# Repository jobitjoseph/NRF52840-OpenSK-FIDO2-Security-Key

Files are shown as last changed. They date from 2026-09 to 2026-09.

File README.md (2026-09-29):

# Build Your Own FIDO2 Security Key with nRF52840 and OpenSK

An open-source USB FIDO2 security key built around the **Nordic nRF52840** and **Google's OpenSK** firmware.

This project demonstrates how to build a hardware-backed authentication device that can be used with websites and services supporting **FIDO2 / WebAuthn**.

The custom hardware uses the nRF52840's native USB interface and hardware-assisted cryptography to implement the security-key functionality. The device communicates with the host computer over USB and keeps the credential's private key on the security key rather than transferring it to the computer or website.

---

## Features

- FIDO2 / WebAuthn authentication
- nRF52840-based custom hardware
- OpenSK open-source security-key firmware
- USB HID FIDO2 transport
- Hardware-assisted cryptography using the nRF52840
- Credential private key remains on the security key
- USB DFU / UF2 firmware updates
- Custom capacitive touch input for user presence
- RGB LED for status indication
- Custom compact PCB
- Open-source hardware and firmware modifications

---

## How It Works

The security key acts as a FIDO2 authenticator between the browser and the website.

During registration, the security key generates a unique credential key pair:

```text
                 Registration

Website
   │
   │ Registration request
   ▼
Browser
   │
   │ FIDO2 / CTAP2 over USB HID
   ▼
OpenSK on nRF52840
   │
   ├── Generate credential key pair
   │
   ├── Private key ──► Stored on security key
   │
   └── Public key ───► Website

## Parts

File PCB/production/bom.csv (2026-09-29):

Designator | Footprint | Quantity | Value | LCSC Part #
C1, C2, C3 | 0402 | 3 | 4.7uF | C1779
C10 | 0402 | 1 | 100pF | C1546
C11, C9 | 0402 | 2 | 1uF | C52923
C12, C13 | 0402 | 2 | 8pF | C32949
C14, C4, C5, C6, C7 | 0402 | 5 | 100nF | C14663
C15 | 0402 | 1 | 10nF | C1710
C8 | 0402 | 1 | 820pF | C1523
CR1 | TVS-SP05_LTF-L | 1 | SP0503BAHTG | C7074
J1 | SAMESKY_UP32-C-F-G-FL-1-P24 | 1 | UP32-C-F-G-FL-1-P24 | C42453853
J2 | PinHeader_1x01_P2.54mm_Vertical | 1 | Conn_01x01
R1 | 0402 | 1 | 0R | C17168
R2, R3 | 0402 | 2 | 5.1K | C25905
R4, R5, R6 | 0402 | 3 | 220R | C25091
R7 | 0402 | 1 | 10K | C25744
SW1 | SW-SMD_4P-L4.5-W4.5-P3.50-LS5.0 | 1 | TS45055A | C412371
TP1, TP2, TP3, TP4, TP5, TP6 | TestPoint_Pad_D1.0mm | 6 | TestPoint
U1 | XCVR_NRF52840-QIAA-R | 1 | NRF52840-QIAA | NRF52840-QIAA-R
U2 | SOT-23-6 | 1 | AT42QT1010-TSHR | C74512
U3 | LED-SMD_4P-L1.6-W1.5-BL-2 | 1 | XL-1615RGBC-YG | C5440642
Y1 | Crystal_SMD_2016-4Pin_2.0x1.6mm | 1 | 32MHz | C383840

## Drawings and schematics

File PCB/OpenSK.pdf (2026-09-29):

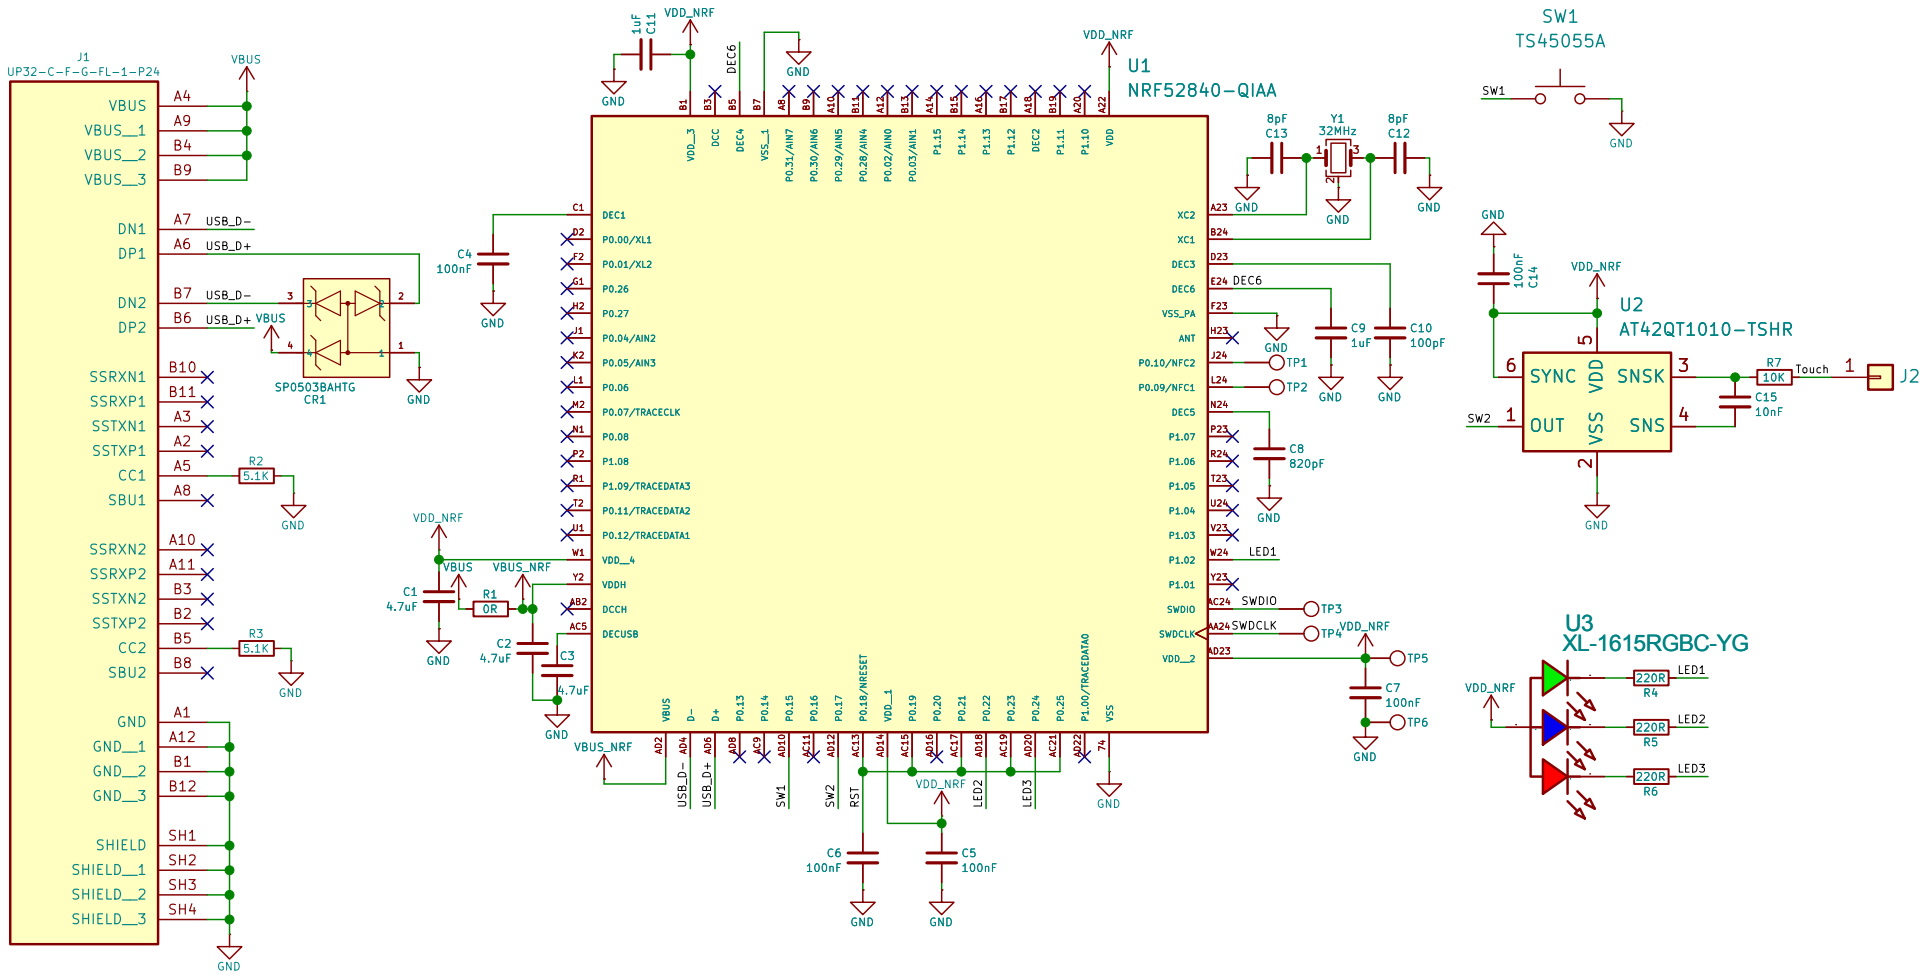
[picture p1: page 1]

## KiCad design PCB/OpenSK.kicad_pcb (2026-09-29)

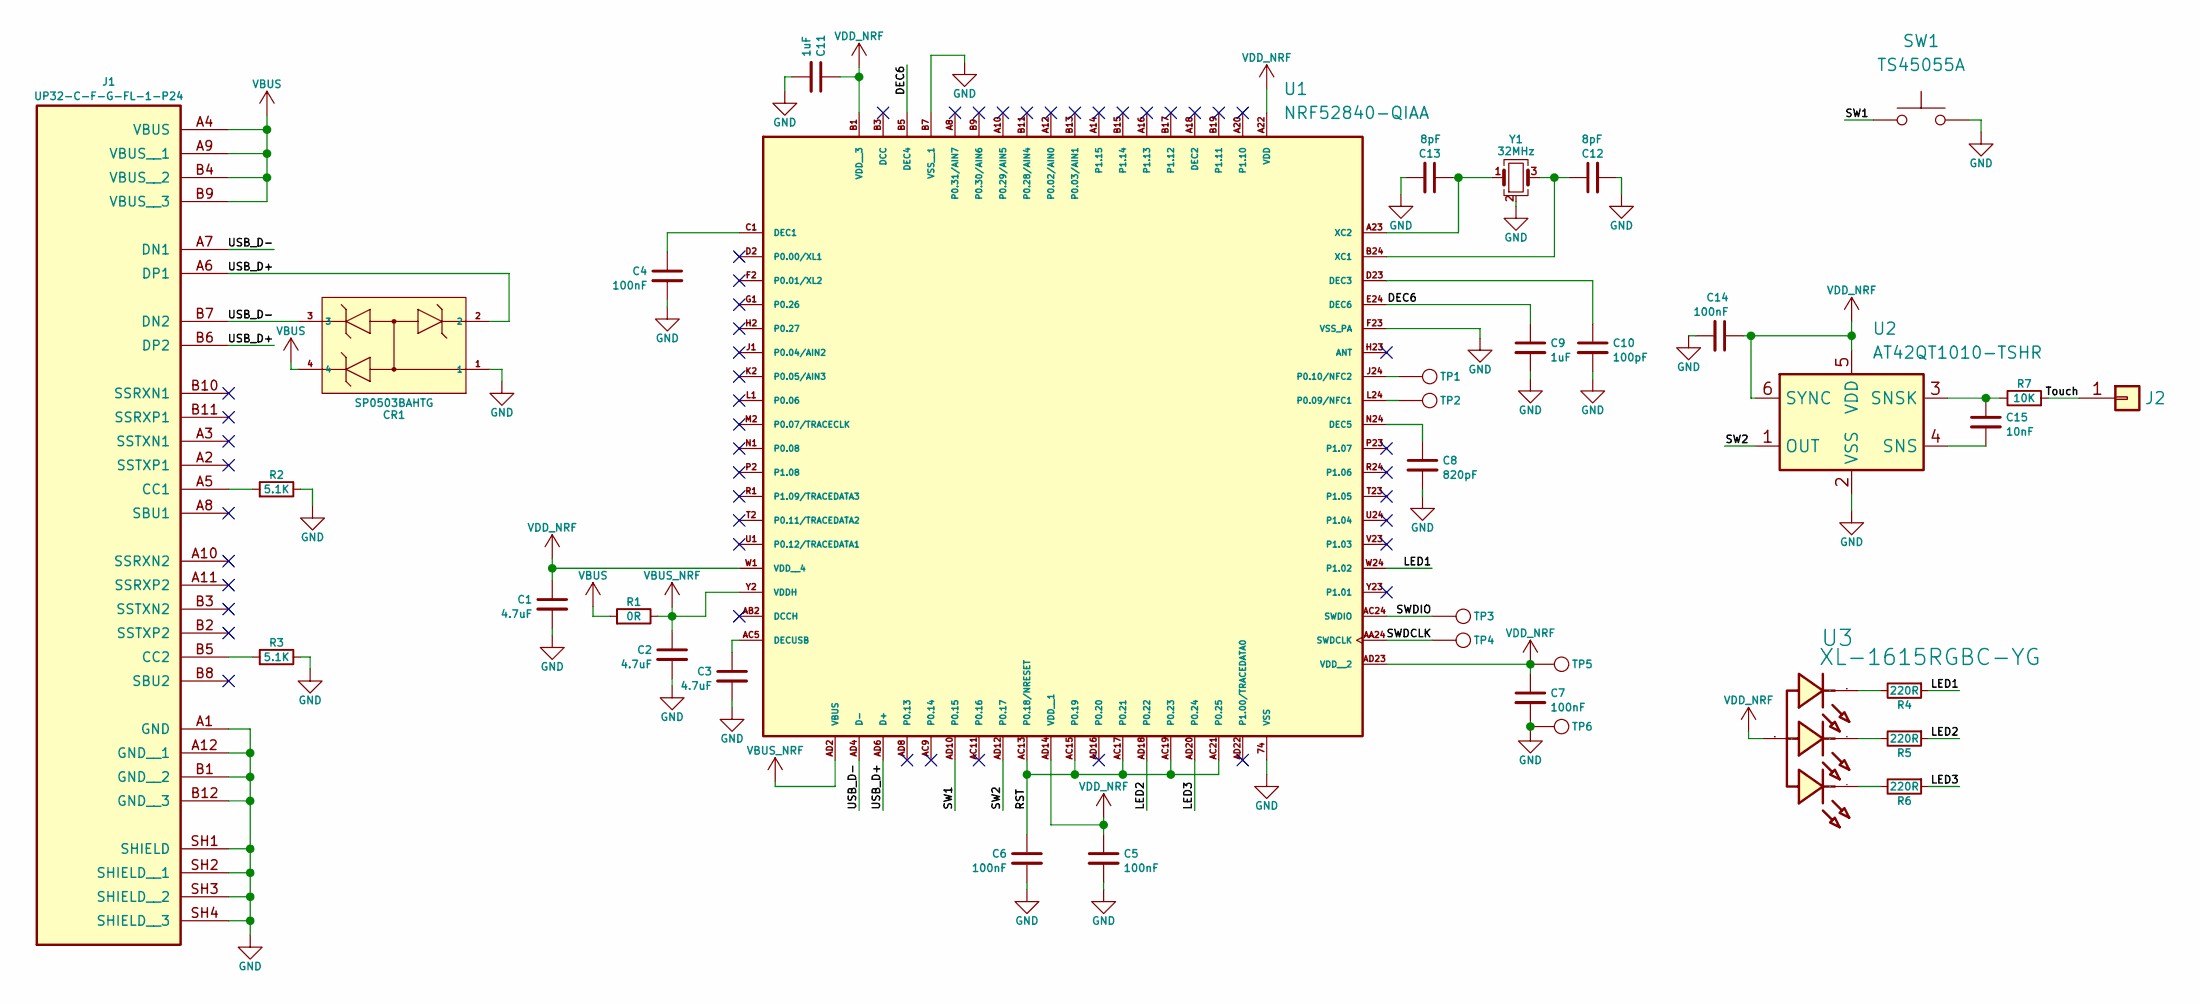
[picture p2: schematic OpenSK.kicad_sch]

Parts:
C1, C2, C3: 4.7uF; C_0402_1005Metric; LCSC Part # C1779
C4, C5, C6, C7, C14: 100nF; C_0402_1005Metric; LCSC Part # C14663
C8: 820pF; C_0402_1005Metric; LCSC Part # C1523
C9, C11: 1uF; C_0402_1005Metric; LCSC Part # C52923
C10: 100pF; C_0402_1005Metric; LCSC Part # C1546
C12, C13: 8pF; C_0402_1005Metric; LCSC Part # C32949
C15: 10nF; C_0402_1005Metric; LCSC Part # C1710
CR1: SP0503BAHTG; TVS-SP05_LTF-L; LCSC Part # C7074
J1: UP32-C-F-G-FL-1-P24; SAMESKY_UP32-C-F-G-FL-1-P24; PARTREV 1.01; LCSC Part # C42453853
J2: Conn_01x01; PinHeader_1x01_P2.54mm_Vertical
R1: 0R; R_0402_1005Metric; LCSC Part # C17168
R2, R3: 5.1K; R_0402_1005Metric; LCSC Part # C25905
R4, R5, R6: 220R; R_0402_1005Metric; LCSC Part # C25091
R7: 10K; R_0402_1005Metric; LCSC Part # C25744
SW1: TS45055A; SW-SMD_4P-L4.5-W4.5-P3.50-LS5.0; LCSC Part # C412371
TP1, TP2, TP3, TP4, TP5, TP6: TestPoint; TestPoint_Pad_D1.0mm
U1: NRF52840-QIAA; XCVR_NRF52840-QIAA-R; PARTREV v1.1; LCSC Part # NRF52840-QIAA-R
U2: AT42QT1010-TSHR; SOT-23-6; LCSC Part # C74512
U3: XL-1615RGBC-YG; LED-SMD_4P-L1.6-W1.5-BL-2; Manufacturer Part XL-1615RGBC-YG; LCSC Part # C5440642
Y1: 32MHz; Crystal_SMD_2016-4Pin_2.0x1.6mm; LCSC Part # C383840

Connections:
/DEC6: C9.1, U1.B5 (DEC4), U1.E24 (DEC6)
/LED1: R4.1, U1.W24 (P1.02)
/LED2: R5.1, U1.AD18 (P0.22)
/LED3: R6.1, U1.AD20 (P0.24)
/RST: C6.1, U1.AC13 (P0.18/NRESET), U1.AC15 (P0.19), U1.AC17 (P0.21), U1.AC19 (P0.23), U1.AC21 (P0.25)
/SW1: SW1.2, U1.AD10 (P0.15)
/SW2: U1.AD12 (P0.17), U2.1 (OUT)
/SWDCLK: TP4.1 (1_1), U1.AA24 (SWDCLK)
/SWDIO: TP3.1 (1_1), U1.AC24 (SWDIO)
/Touch: J2.1 (Pin_1_1), R7.1
/USB_D+: CR1.2, J1.A6 (DP1), J1.B6 (DP2), U1.AD6 (D+)
/USB_D-: CR1.3, J1.A7 (DN1), J1.B7 (DN2), U1.AD4 (D-)
GND: C1.2, C2.2, C3.2, C4.2, C5.2, C6.2, C7.2, C8.2, C9.2, C10.2, C11.2, C12.2, C13.2, C14.2, CR1.1, J1.A1 (GND), J1.A12 (GND__1), J1.B1 (GND__2), J1.B12 (GND__3), J1.SH1 (SHIELD), J1.SH2 (SHIELD__1), J1.SH3 (SHIELD__2), J1.SH4 (SHIELD__3), R2.2, R3.2, SW1.1, TP6.1 (1_1), U1.74 (VSS), U1.B7 (VSS__1), U1.F23 (VSS_PA), U2.2 (VSS), Y1.2 (G), Y1.4 (G)
unnamed: J1.A5 (CC1), R2.1
unnamed: J1.B5 (CC2), R3.1
unnamed: R4.2, U3.4 (K)
unnamed: R5.2, U3.3 (K)
unnamed: R6.2, U3.2 (K)
unnamed: C4.1, U1.C1 (DEC1)
unnamed: C10.1, U1.D23 (DEC3)
unnamed: C8.1, U1.N24 (DEC5)
unnamed: C3.1, U1.AC5 (DECUSB)
unnamed: TP2.1 (1_1), U1.L24 (P0.09/NFC1)
unnamed: TP1.1 (1_1), U1.J24 (P0.10/NFC2)
unnamed: C12.1, U1.B24 (XC1), Y1.3
unnamed: C13.1, U1.A23 (XC2), Y1.1
unnamed: C15.2, U2.4 (SNS)
unnamed: C15.1, R7.2, U2.3 (SNSK)
VBUS: CR1.4, J1.A4 (VBUS), J1.A9 (VBUS__1), J1.B4 (VBUS__2), J1.B9 (VBUS__3), R1.1
VBUS_NRF: C2.1, R1.2, U1.AD2 (VBUS), U1.Y2 (VDDH)
VDD_NRF: C1.1, C5.1, C7.1, C11.1, C14.1, TP5.1 (1_1), U1.A22 (VDD), U1.AD14 (VDD__1), U1.AD23 (VDD__2), U1.B1 (VDD__3), U1.W1 (VDD__4), U2.5 (VDD), U2.6 (SYNC), U3.1 (A)

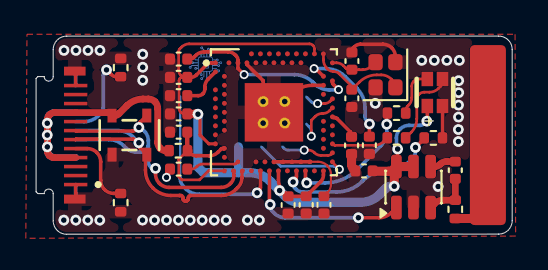
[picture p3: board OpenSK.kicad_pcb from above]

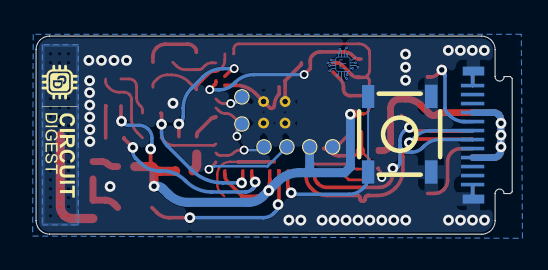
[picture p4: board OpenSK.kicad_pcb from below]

Board: 2 copper layers, 26.5 x 11.0 mm, 36 parts (7 on the bottom side), 31 nets.
